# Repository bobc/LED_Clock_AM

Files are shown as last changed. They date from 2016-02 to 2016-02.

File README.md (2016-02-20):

# About LED_Clock_AM
An LED clock with Arduino Mini/Micro

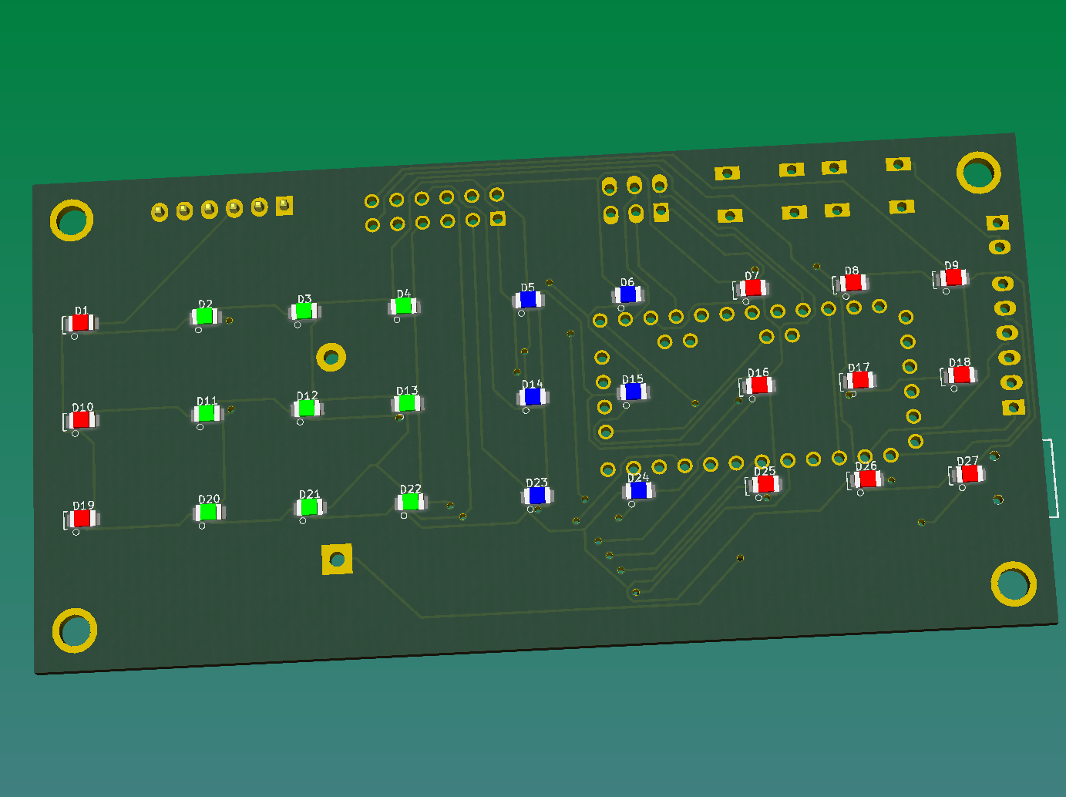
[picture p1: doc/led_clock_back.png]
LED_Clock_AM


Replica of "Tix(tm)" style LED clock with accurate Maxim Real Time Clock chip (DS3231). Uses an Arduino Micro or Mini (or compatible).

##Copyright

Open Source Hardware, licensed with CERN OHL.

Copyright (c) 2016 Bob Cousins  

This documentation describes Open Hardware and is licensed under the
CERN OHL v. 1.1.  You may redistribute and modify this documentation
under the terms of the CERN OHL v.1.1. (http://ohwr.org/cernohl). This
documentation is distributed WITHOUT ANY EXPRESS OR IMPLIED WARRANTY,
INCLUDING OF MERCHANTABILITY, SATISFACTORY QUALITY AND FITNESS FOR A
PARTICULAR PURPOSE. Please see the CERN OHL v.1.1 for applicable
conditions

You can find a copy of the CERN OHL v.1.1 in the file "LICENSE". Please also read "LICENSE.HOWTO".

##External dependencies

- KiCad 4.0.x, with included symbol libaries and 3D symbols http://kicad-pcb.org/download/
- KiCad footprints (4.0.0 release)  
- RMC libraries
- Walter Lain libraries  http://smisioto.no-ip.org/elettronica/kicad/kicad-en.htm

##Fabrication outputs

Gerbers are in the "gerbers" folder.  
The zip file is for submission to ITeadMall, probably could be used for other fab houses.  
The gvp file is for use with gerbv (http://gerbv.geda-project.org/).

OSHWA KiCad  OSI

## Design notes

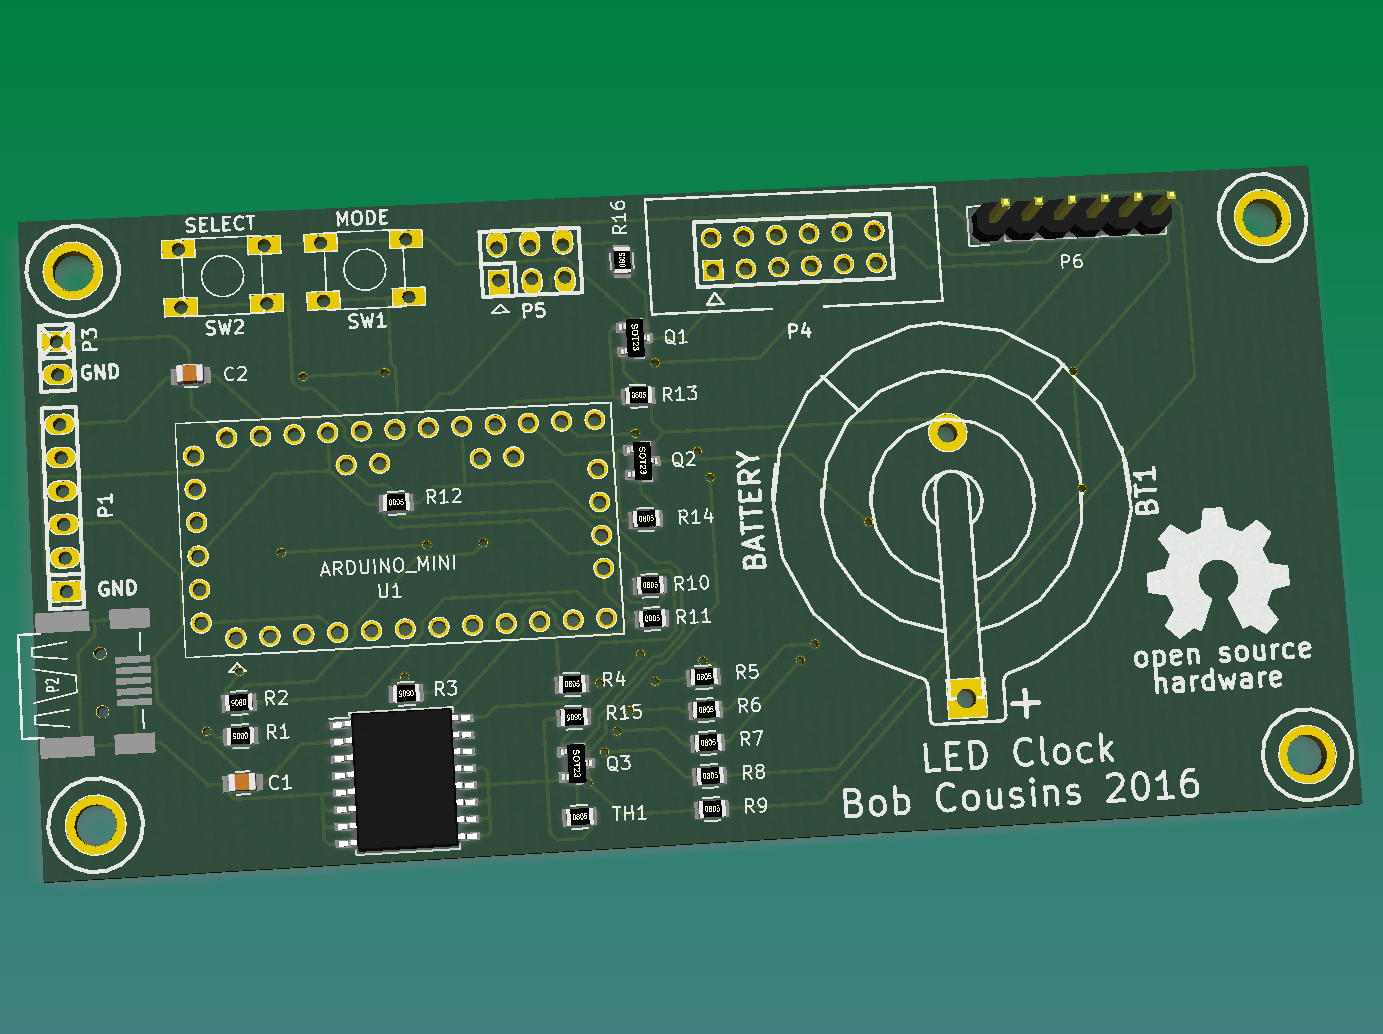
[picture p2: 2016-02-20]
doc/led_clock_front.png

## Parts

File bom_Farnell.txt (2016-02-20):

1650672,1
1414663,10
5790840,12
5790852,9
2497350,6
1125348,1
9845330,3
1469899,9
1469923,10
1469856,10
2402398,2
1672287,1
2115248,1

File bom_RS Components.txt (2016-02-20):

430675,1
6480941,10
4860468,25
4356767,50
6910442,6
6661099,5
6710324,10
6791096,50
6791496,50
6790816,50
7856245,2
6974610,5
7327573,1

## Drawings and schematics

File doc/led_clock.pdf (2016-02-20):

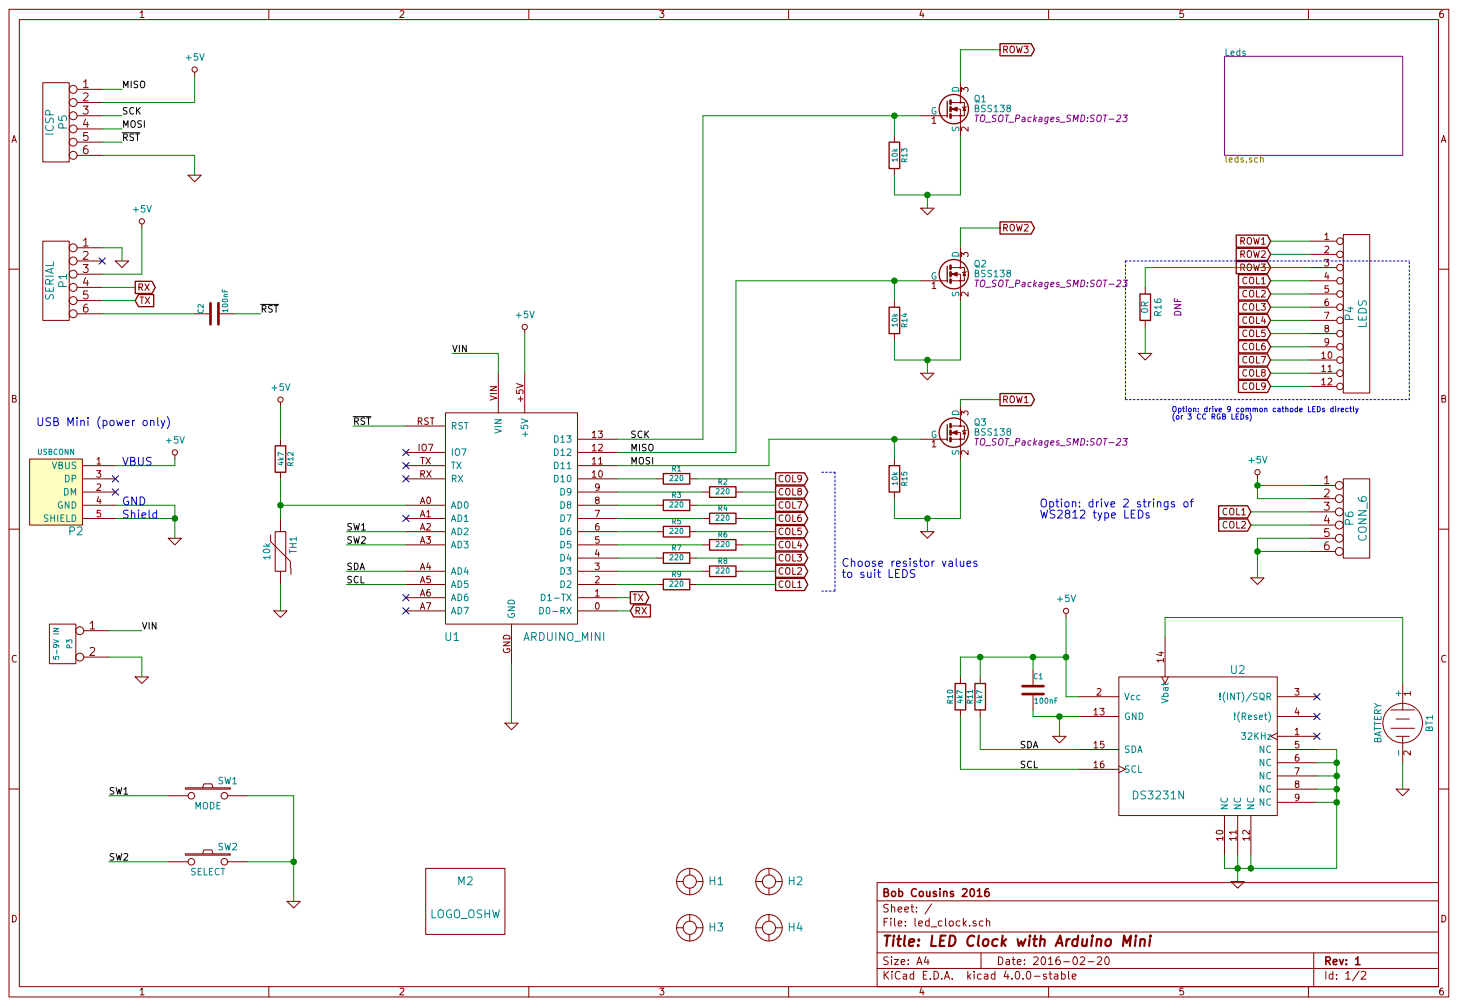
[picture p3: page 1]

+5V COL1 COL2 USB Mini (power only)

(or 3 CC RGB LEDs) Option: drive 2 strings of

File: led_clock.sch Sheet: / Bob Cousins 2016

Id: 1/2 Title: LED Clock with Arduino Mini

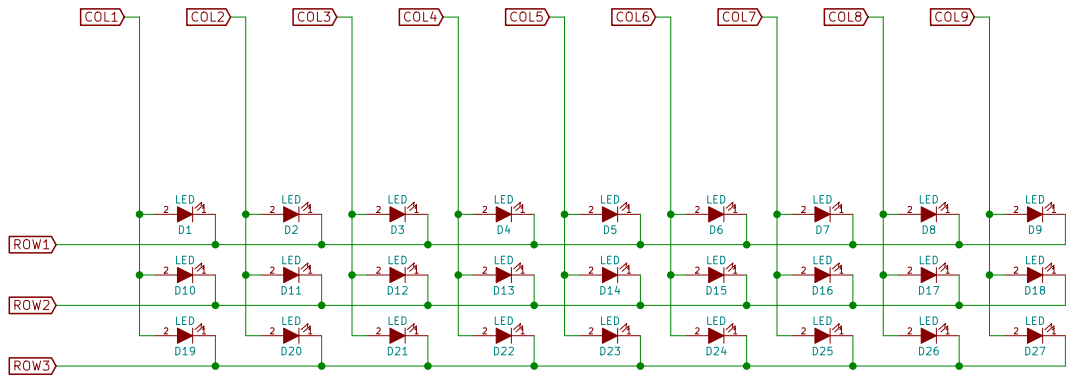
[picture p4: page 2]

Id: 2/2 Title: LED Clock with Arduino Mini File: leds.sch Sheet: /Leds/

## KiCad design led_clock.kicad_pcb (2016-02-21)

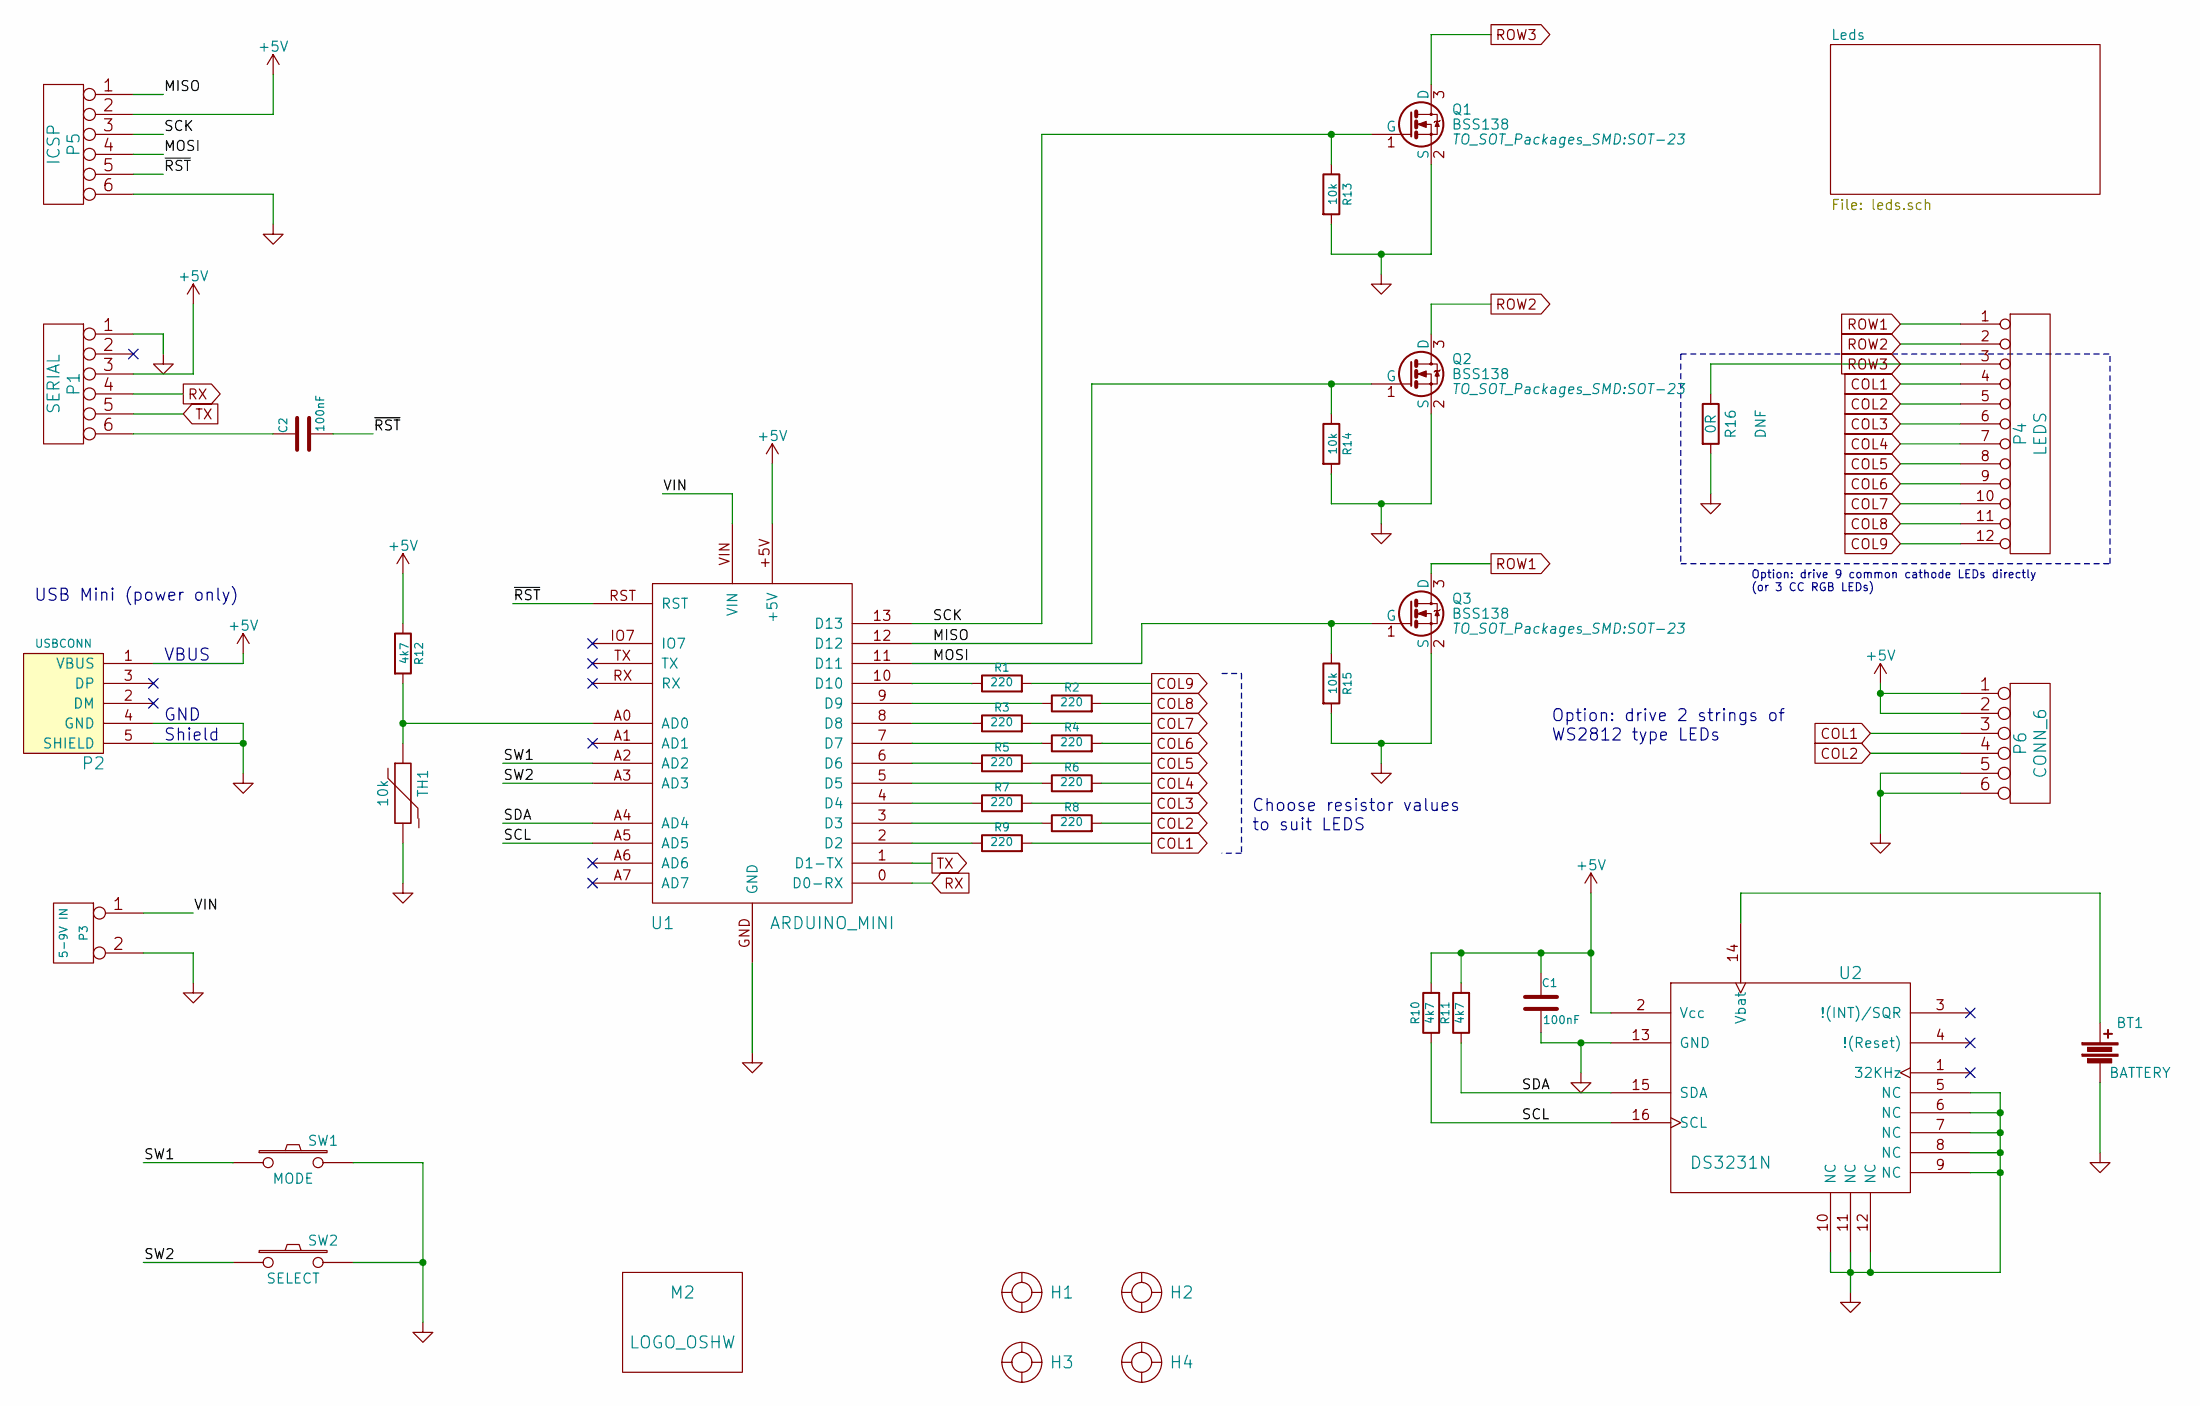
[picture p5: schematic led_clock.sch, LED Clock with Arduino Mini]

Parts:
BT1: BATTERY; keystone_106
C1, C2: 100nF; C_0805
H1, H2, H3, H4: HOLE_RMC; HOLE_M3
M2: LOGO_OSHW; OSHW_logo_2
P1: SERIAL; pin_strip_6
P2: USBCONN; CONN_MiniAB_SMT_RMC
P3: 5-9V IN; pin_strip_2
P4: LEDS; PIN_ARRAY_6x2_RMC
P5: ICSP; pin_strip_3x2
P6: CONN_6; Pin_Header_Straight_1x06
Q1, Q2, Q3: BSS138; SOT-23
R1, R2, R3, R4, R5, R6, R7, R8, R9: 220; R_0805
R10, R11, R12: 4k7; R_0805
R13, R14, R15: 10k; R_0805
R16: 0R; R_0805
SW1: MODE; SW_6x6_MULTI
SW2: SELECT; SW_6x6_MULTI
TH1: 10k; R_0805
U1: ARDUINO_MINI
U2: DS3231N; SOIC-16_7.5x10.3mm_Pitch1.27mm

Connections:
+5V: C1.1, P1.3, P2.1 (VBUS), P5.2, P6.1, P6.2, R10.2, R11.2, R12.1, U1.+5V, U2.2 (Vcc)
/MISO: P5.1, Q2.1 (G), R14.1, U1.12 (D12)
/MOSI: P5.4, Q3.1 (G), R15.1, U1.11 (D11)
/SCK: P5.3, Q1.1 (G), R13.1, U1.13 (D13)
/SCL: R10.1, U1.A5 (AD5), U2.16 (SCL)
/SDA: R11.1, U1.A4 (AD4), U2.15 (SDA)
/SW1: SW1.1, U1.A2 (AD2)
/SW2: SW2.1, U1.A3 (AD3)
/VIN: P3.1, U1.VIN
/~RST: C2.2, P5.5, U1.RST
COL1: P4.4, P6.3, R9.2; also elsewhere on the board
COL2: P4.5, P6.4, R8.2; also elsewhere on the board
COL3: P4.6, R7.2; also elsewhere on the board
COL4: P4.7, R6.2; also elsewhere on the board
COL5: P4.8, R5.2; also elsewhere on the board
COL6: P4.9, R4.2; also elsewhere on the board
COL7: P4.10, R3.2; also elsewhere on the board
COL8: P4.11, R2.2; also elsewhere on the board
COL9: P4.12, R1.2; also elsewhere on the board
GND: BT1.2, C1.2, P1.1, P2.4 (GND), P2.5 (SHIELD), P3.2 (PM), P5.6, P6.5, P6.6, Q1.2 (S), Q2.2 (S), Q3.2 (S), R13.2, R14.2, R15.2, R16.2, SW1.2, SW2.2, TH1.2, U1.GND, U2.5 (NC), U2.6 (NC), U2.7 (NC), U2.8 (NC), U2.9 (NC), U2.10 (NC), U2.11 (NC), U2.12 (NC), U2.13 (GND)
unnamed: BT1.1, U2.14 (Vbat)
unnamed: C2.1, P1.6
unnamed: R1.1, U1.10 (D10)
unnamed: R2.1, U1.9 (D9)
unnamed: R3.1, U1.8 (D8)
unnamed: R4.1, U1.7 (D7)
unnamed: R5.1, U1.6 (D6)
unnamed: R6.1, U1.5 (D5)
unnamed: R7.1, U1.4 (D4)
unnamed: R8.1, U1.3 (D3)
unnamed: R9.1, U1.2 (D2)
unnamed: R12.2, TH1.1, U1.A0 (AD0)
ROW1: P4.1, Q3.3 (D); also elsewhere on the board
ROW2: P4.2, Q2.3 (D); also elsewhere on the board
ROW3: P4.3, Q1.3 (D), R16.1; also elsewhere on the board
RX: P1.4, U1.0 (D0-RX)
TX: P1.5, U1.1 (D1-TX)

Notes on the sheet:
USB Mini (power only)
GND
Shield
VBUS
Option: drive 9 common cathode LEDs directly (or 3 CC RGB LEDs)
Option: drive 2 strings of WS2812 type LEDs
Choose resistor values to suit LEDS

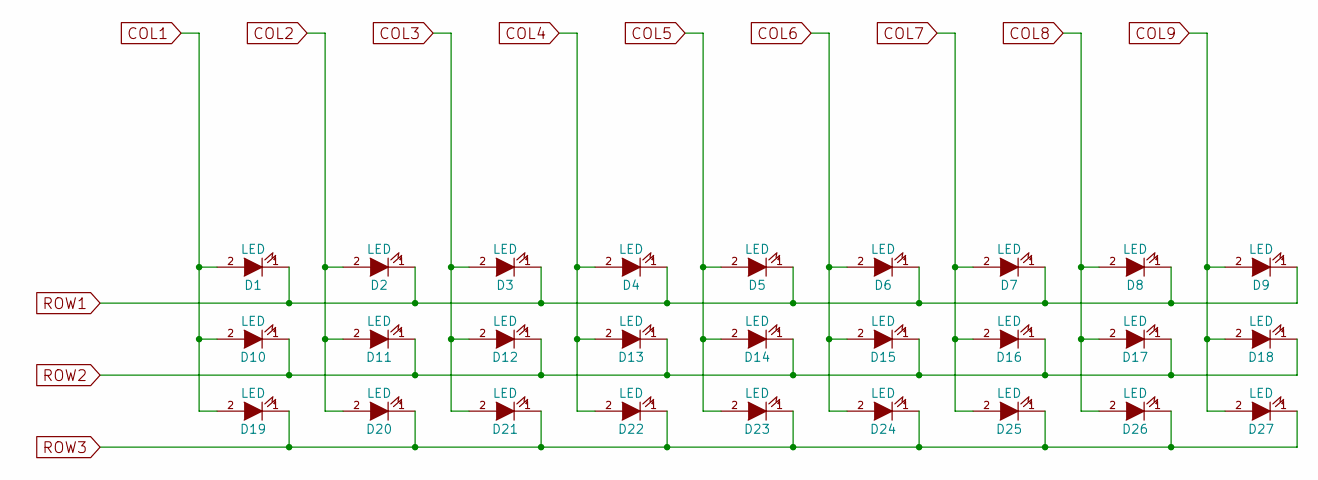
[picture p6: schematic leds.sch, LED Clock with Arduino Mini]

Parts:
D1, D7, D8, D9, D10, D16, D17, D18, D19, D25, D26, D27: LED; LED-0805_RED
D2, D3, D4, D11, D12, D13, D20, D21, D22: LED; LED-0805_GREEN
D5, D6, D14, D15, D23, D24: LED; LED-0805_BLUE

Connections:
COL1: D1.2 (A), D10.2 (A), D19.2 (A); also elsewhere on the board
COL2: D2.2 (A), D11.2 (A), D20.2 (A); also elsewhere on the board
COL3: D3.2 (A), D12.2 (A), D21.2 (A); also elsewhere on the board
COL4: D4.2 (A), D13.2 (A), D22.2 (A); also elsewhere on the board
COL5: D5.2 (A), D14.2 (A), D23.2 (A); also elsewhere on the board
COL6: D6.2 (A), D15.2 (A), D24.2 (A); also elsewhere on the board
COL7: D7.2 (A), D16.2 (A), D25.2 (A); also elsewhere on the board
COL8: D8.2 (A), D17.2 (A), D26.2 (A); also elsewhere on the board
COL9: D9.2 (A), D18.2 (A), D27.2 (A); also elsewhere on the board
ROW1: D1.1 (K), D2.1 (K), D3.1 (K), D4.1 (K), D5.1 (K), D6.1 (K), D7.1 (K), D8.1 (K), D9.1 (K); also elsewhere on the board
ROW2: D10.1 (K), D11.1 (K), D12.1 (K), D13.1 (K), D14.1 (K), D15.1 (K), D16.1 (K), D17.1 (K), D18.1 (K); also elsewhere on the board
ROW3: D19.1 (K), D20.1 (K), D21.1 (K), D22.1 (K), D23.1 (K), D24.1 (K), D25.1 (K), D26.1 (K), D27.1 (K); also elsewhere on the board

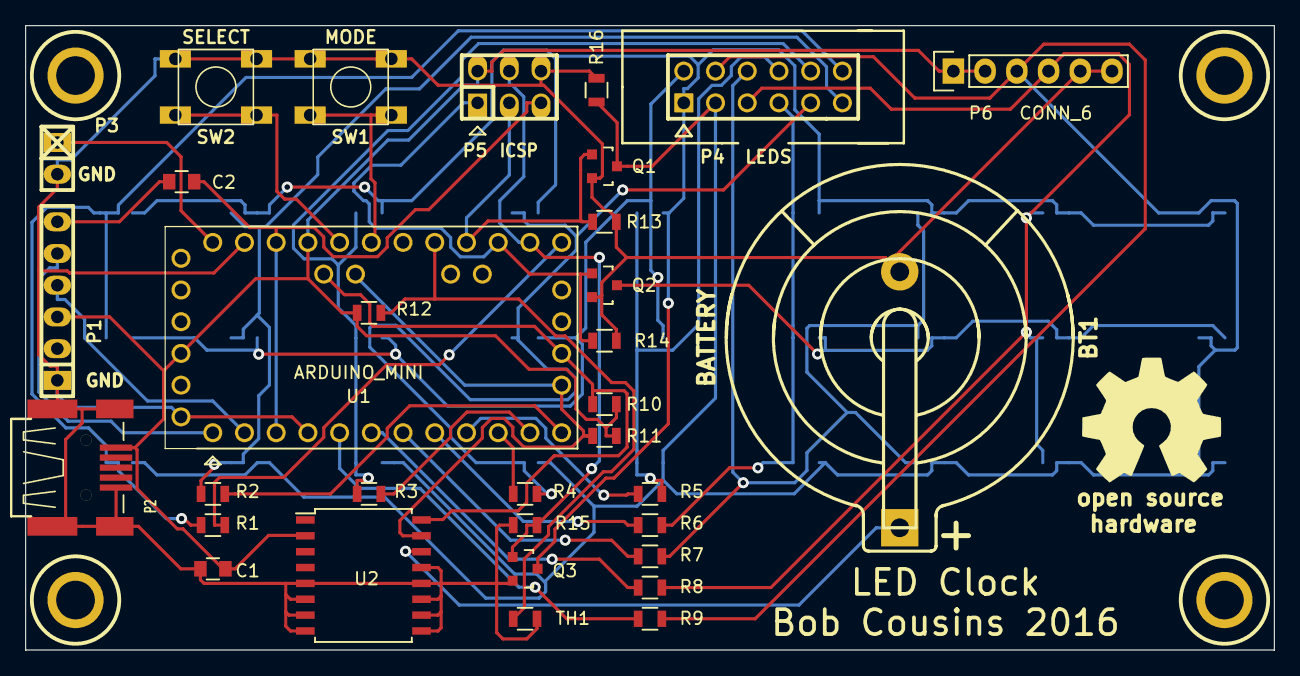
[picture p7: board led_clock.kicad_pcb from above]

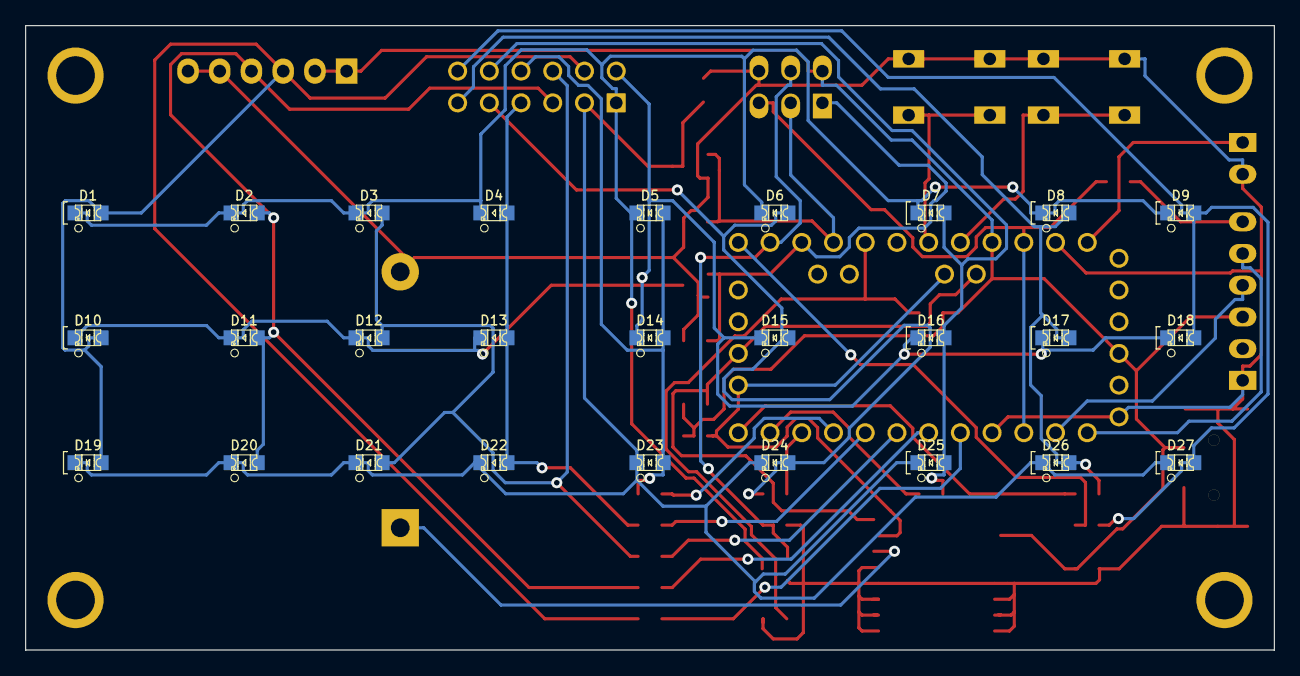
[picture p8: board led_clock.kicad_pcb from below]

Board: 2 copper layers, 100.0 x 50.0 mm, 65 parts (27 on the bottom side), 37 nets.

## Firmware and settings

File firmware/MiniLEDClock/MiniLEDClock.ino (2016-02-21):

/* 
   Contributors:
   Copyright (c) 2016 Bob Cousins bobcousins42@googlemail.com       
*/

/* All rights reserved.

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
  THIS SOFTWARE IS PROVIDED BY THE COPYRIGHT HOLDERS AND CONTRIBUTORS "AS IS"
  AND ANY EXPRESS OR IMPLIED WARRANTIES, INCLUDING, BUT NOT LIMITED TO, THE
  IMPLIED WARRANTIES OF MERCHANTABILITY AND FITNESS FOR A PARTICULAR PURPOSE
  ARE DISCLAIMED. IN NO EVENT SHALL THE COPYRIGHT OWNER OR CONTRIBUTORS BE
  LIABLE FOR ANY DIRECT, INDIRECT, INCIDENTAL, SPECIAL, EXEMPLARY, OR
  CONSEQUENTIAL DAMAGES (INCLUDING, BUT NOT LIMITED TO, PROCUREMENT OF
  SUBSTITUTE GOODS OR SERVICES; LOSS OF USE, DATA, OR PROFITS; OR BUSINESS
  INTERRUPTION) HOWEVER CAUSED AND ON ANY THEORY OF LIABILITY, WHETHER IN
  CONTRACT, STRICT LIABILITY, OR TORT (INCLUDING NEGLIGENCE OR OTHERWISE)
  ARISING IN ANY WAY OUT OF THE USE OF THIS SOFTWARE, EVEN IF ADVISED OF THE
  POSSIBILITY OF SUCH DAMAGE.
*/

// **************************************************************************
//
//    LED Clock "Tix(tm)" style
//    
//    with Arduino Pro Mini
//
// **************************************************************************


#include <inttypes.h>

#include <Wire.h>  
#include <Time.h>
#include <DS3232RTC.h>

#define NUM_COLS  9
#define NUM_ROWS  3

#define BLACK  0x0000
#define RED    0x1
#define GREEN  0x1
#define BLUE   0x1
#define YELLOW 0x1
#define PINK   0x1
#define ORANGE 0x1
#define WHITE  0x1

typedef enum {dm_clock, dm_temperature} tDisplayMode;
typedef enum {ds_domino, ds_random} tDisplayStyle;
typedef enum {btn_none, btn_mode=1, btn_select=2} tButtons;

//
/*
typedef struct  { 
  int  Second; 
  int  Minute; 
  int  Hour; 
  int  Wday;   // day of week, sunday is day 1
  int  Day;
  int  Month; 
  int  Year;   // offset from 1970; 
} tmElements_t;
*/
//

int led_col[NUM_COLS] = {2,3,4,5,6,7,8,9,10 };
int led_row[NUM_ROWS] = {11,12,13};

int row;
//int col_data [NUM_ROWS] = { 0x1FF,0x1ff,0x1ff};

int pixels [NUM_COLS*NUM_ROWS];

// run time options
tDisplayMode  display_mode    = dm_clock;
tDisplayStyle display_style   = ds_random;
int           update_interval = 3;

tmElements_t time_now;
unsigned long last_millis;

int timer1_val, timer1_base;
float cur_temp;

//
int pixels_9 [10] =
{
   0b000000000, 
   0b000010000, 
   0b001000100, 
   0b001010100, 
   0b101000101, 
   0b101010101, 
   0b101101101, 
   0b101111101, 
   0b111101111, 
   0b111111111
};

/*
    x x
    x x
    x x
*/    
int pixels_6 [6] =
{
   0b000000, 
   0b000100, 
   0b010001, 
   0b010101, 
   0b011101, 
   0b110111, 
};

int pixels_3 [4] =
{
   0b000, 
   0b010, 
   0b101, 
   0b111, 
};

void SetColumns (int row)
{
  int j;
  
  for (j = 0; j < NUM_COLS; j++)
  {
    if (get_pixel (j, row) != 0)
      digitalWrite (led_col[j], 1);
    else    
      digitalWrite (led_col[j], 0);
  }
}

int adjust_brightness (int color)
{
  // a stub
  return color;
}  

/***************************************************************************
 pixels are wired as follows
                        col (X)
             0   1  2  3   4  5   6  7  8
        0    O   O  O  O   O  O   O  O  O
row(Y)  1    O   O  O  O   O  O   O  O  O
        2    O   O  O  O   O  O   O  O  O
             |   |  |  |   |  |   ^  ^  ^ minute, units 0-9
             |   |  |  |   ^  ^ minute, tens 0-5    
             |   ^  ^  ^ hour, units 0-9
             ^ hour, tens 0-2
****************************************************************************/


void set_pixel (int x, int y, int color)
{
  pixels [(y*NUM_COLS) + x] = color;
}

int get_pixel (int x, int y)
{
  return pixels [(y*NUM_COLS) + x];
}

int get_random_bits (int total_width, int num_bits)
{
  int bits;
  int new_bit;
  
  bits = 0;
  while (num_bits)
  {
    new_bit = 1 << random (total_width);
    if ((new_bit & bits) == 0)
    {
      bits |= new_bit;
      num_bits--;
    }
  }  
  return bits;
}

void set_digit_x9 (int col, int val, int color)
{
  int x, y;
  int bits;
 
  if (display_style == ds_domino)
    bits = pixels_9 [val];
  else
    bits = get_random_bits (9, val);
  
  color = adjust_brightness(color); 
  
  for (y = NUM_ROWS-1; y>=0; y--)
  {
    for (x = col+2; x >= col; x--)
    {
      if ((bits & 1) != 0)
        set_pixel (x,y, color);
      bits = bits >> 1;  
    }
  }
}

void set_digit_x6 (int col, int val, int color)
{
  int x, y;
  int bits;
 
  if (display_style == ds_domino)
    bits = pixels_6 [val];
  else
    bits = get_random_bits (6, val);
  
  color = adjust_brightness(color); 
  
  for (y = 0; y < NUM_ROWS; y++)
  {
    for (x = col+1; x >= col; x--)
    {
      if ((bits & 1) != 0)
        set_pixel (x,y, color);
      bits = bits >> 1;  
    }
  }
}

void set_digit_x3 (int col, int val, int color)
{
  int y;
  int bits;
 
  if (display_style == ds_domino)
    bits = pixels_3 [val];
  else
    bits = get_random_bits (3, val);
  
  color = adjust_brightness(color); 
  
  for (y = 0; y < NUM_ROWS; y++)
  {
    if ((bits & 1) != 0)
      set_pixel (col, y, color);
    bits = bits >> 1;  
  }
}

void update_display (void)
{
  memset (pixels, 0, sizeof(pixels));

  if (display_mode == dm_clock)  
  {
//#define TEST
#ifdef TEST
    set_digit_x3 (0, time_now.Minute / 10, YELLOW);
    set_digit_x9 (1, time_now.Minute % 10, BLUE);

    set_digit_x6 (4, time_now.Second / 10, GREEN);
    set_digit_x9 (6, time_now.Second % 10, RED);
#else
    set_digit_x3 (0, time_now.Hour / 10, YELLOW);
    set_digit_x9 (1, time_now.Hour % 10, BLUE);

    set_digit_x6 (4, time_now.Minute / 10, GREEN);
    set_digit_x9 (6, time_now.Minute % 10, RED);
#endif
  }
}

ISR(TIMER1_OVF_vect)        // interrupt service routine 
{
  digitalWrite (led_row[row], 0);
  row++;
  if (row==NUM_ROWS)
    row = 0;

  SetColumns (row);
  digitalWrite (led_row[row], 1);
 
  TCNT1 = 65536-timer1_val;   // preload timer
}

void init_timer (void)
{
  // initialize timer1 
  noInterrupts();           // disable all interrupts
  TCCR1A = 0;
  TCCR1B = 0;

  // Set timer1_counter to the correct value for our interrupt interval
  // CPU freq=16MHz
  // use prescaler = 8, 
  timer1_base = 16000000 / 8 / 200;
  
  timer1_val = timer1_base;
  
  TCNT1 = 65536-timer1_val;   // preload timer
  TCCR1B |= (1 << CS11);    // prescaler = 8
  TIMSK1 |= (1 << TOIE1);   // enable timer overflow interrupt
  interrupts();             // enable all interrupts
}

// CLI
void show_help(void)
{
  Serial.print ("> ");
}

char cmd_buf [32];
byte cmd_len;

#define CR 13
#define LF 10


char *get_int (uint8_t *pValue, char *pNext)
{
  // skip white space
  while (*pNext && (*pNext == ' ') )
  {
    pNext ++;
  }
  
  //
  if (*pNext == 0)
    // reached end of string
    return NULL;
  else
  {  
    *pValue = 0;

    if (isdigit (*pNext))
    {
      *pValue = (*pValue * 10) + (*pNext - '0');
      pNext ++;
      while (*pNext && isdigit (*pNext) )
      {
        *pValue = (*pValue * 10) + (*pNext - '0');
        pNext ++;
      }
    }
    else
    {
       // junk?
      while (*pNext && (*pNext != ' ') )
      {
        pNext ++;
      }
    }
  }
  
  return pNext;
}

void set_time (char *pBuf)
{
  Serial.print("set time ");
  pBuf = get_int (&time_now.Hour, pBuf);
  pBuf = get_int (&time_now.Minute, pBuf);
  pBuf = get_int (&time_now.Second, pBuf);
  
  RTC.writeTime(time_now);
  print_time();
}

void set_date (char *pBuf)
{
  Serial.print("set date ");
  pBuf = get_int (&time_now.Year, pBuf);
  pBuf = get_int (&time_now.Month, pBuf);
  pBuf = get_int (&time_now.Day, pBuf);
  
//!  RTC.writeDate(time_now);
  print_date();
}

void check_input (void)
{
  int ch = Serial.read();
  
  if (ch!=-1)
  {
     if ( (ch==CR)|| (ch==LF))
     {
       if (cmd_len>0)
       {
         cmd_buf[cmd_len] = '\0';
         Serial.println (cmd_buf);
         
         if (strncmp (cmd_buf, "time", 4)==0)
         {
           if (cmd_len == 4)
             print_time();
           else
             set_time (&cmd_buf[4]);
         }
         else if (strncmp (cmd_buf, "date", 4)==0)
         {
           if (cmd_len == 4)
             print_date();
           else
             set_date (&cmd_buf[4]);
         }
         else if (strncmp (cmd_buf, "temp", 4)==0)
         {
             print_temperature();
         }         
         else if (strncmp (cmd_buf, "?", 1)==0)
         {
           Serial.println ("Commands:");
           Serial.println ("date            show current date");
           Serial.println ("date yy mm dd   set date");
           Serial.println ("time            show current time");
           Serial.println ("time hh mm ss   set time");
           Serial.println ("temp            show current IC temperature");
         }
       }
       else
         Serial.println();
       Serial.print ("> ");
       
       cmd_len = 0;
     }
     else
     {
       if (cmd_len < sizeof(cmd_buf))
       {
         cmd_buf[cmd_len++] = ch;
       }
     }
  }
}

void setup() {

  int j;

  Serial.begin(115200);
  
  for (j = 0; j < NUM_COLS; j++)
  {
    pinMode (led_col[j], OUTPUT);
    if (j < NUM_ROWS)
    {
      pinMode (led_row[j], OUTPUT);
      digitalWrite (led_row[j], 0);
    }
  }

  //
  get_time();

  //
  SetColumns (0);
  row = 0;
  
  init_timer();
  
  Serial.println ("Type ? for help\n");
}


//
void get_time (void)
{
    // Read the current time
    RTC.read(time_now);
}

void print_time (void)
{
  char buf [12];
  sprintf (buf, "%02d:%02d:%02d", time_now.Hour, time_now.Minute, time_now.Second);
  Serial.println (buf);
}

void print_date (void)
{
  char buf [16];
  sprintf (buf, "%04d-%02d-%02d", tmYearToCalendar(time_now.Year), time_now.Month, time_now.Day);
  Serial.println (buf);
}

void print_temperature (void)
{
  tpElements_t tp;

  RTC.readTemperature(tp);
  if (tp.Temp != NO_TEMPERATURE) 
  {
      float temp = tp.Temp + (tp.Decimal / 100);
      Serial.print(temp);
      Serial.println("'C");
  } else {
      Serial.println("Temperature is not available");
  }
}

// Some code from RepRap
//
// BETA is the B value
// RS is the value of the series resistor in ohms
// R_INF is R0.exp(-BETA/T0), where R0 is the thermistor resistance at T0 (T0 is in kelvin)
// Normally T0 is 298.15K (25 C).  If you write that expression in brackets in the #define the compiler 
// should compute it for you (i.e. it won't need to be calculated at run time).

// If the A->D converter has a range of 0..16383 and the measured voltage is V (between 0 and 16383)
// then the thermistor resistance, R = V.RS/(16383 - V)
// and the temperature, T = BETA/ln(R/R_INF)
// To get degrees celsius (instead of kelvin) add -273.15 to T

#define ABS_ZERO -273.15
#define AD_RANGE 1023

// AVK 10k NB12K00103KBB
// RS  697-4610
#define E_BETA 3630.0
#define E_RS 4700.0
#define E_R_INF ( 10000.0*exp(-E_BETA/298.15) )

float analog_to_temp (int raw, float beta, float rs, float r_inf)
{
   return ABS_ZERO + beta / log( (raw*rs/(AD_RANGE - raw) )/r_inf );
}
void read_thermistor (void)
{
  cur_temp = analog_to_temp (analogRead (0), E_BETA, E_RS, E_R_INF);
}

void loop() 
{
  check_input();
  
//  read_thermistor();
  
  if (millis() - last_millis > 1000)
  {
      // print_time();

      // Serial.print(cur_temp); Serial.println("'C");

      //      
      last_millis = millis();
    
      // increment time
      time_now.Second++;
      if (time_now.Second == 60)
      {  
        time_now.Second = 0;
        time_now.Minute ++;
        if (time_now.Minute == 60)
        {
          time_now.Minute = 0;
          time_now.Hour++;
          if (time_now.Hour == 24)
            time_now.Hour = 0;
            
          get_time();
        }
      }
      
      if ((time_now.Second % update_interval) == 0)
      {
        update_display();
      }
  }
}

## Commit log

2016-02-20 Version 1
    [led_clock-B_Cu.gbl, led_clock-B_Mask.gbs, led_clock-B_SilkS.gbo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]
2016-02-21 Remove old gerbers
    [led_clock-B_Cu.gbl, led_clock-B_Mask.gbs, led_clock-B_SilkS.gbo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]
2016-02-21 New gerbers; fix problem with USB connector not connected to GND
    [led_clock-B.Cu.gbl, led_clock-B.Mask.gbs, led_clock-B.SilkS.gbo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]
2016-02-21 Remove references to unused libs/symbols
    [led_clock.sch, leds.sch]
2016-02-21 Fix up paths for 3D models
    [led_clock.kicad_pcb]
2016-02-21 Add sketch for Arduino
